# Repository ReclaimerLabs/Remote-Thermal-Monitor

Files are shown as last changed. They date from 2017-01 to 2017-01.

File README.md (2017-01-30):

# Introduction

This board is a remote thermocouple monitor. It is pretty much a direct implementation of [**App Note SBAA189**](http://www.ti.com/lit/an/sbaa189/sbaa189.pdf) from TI. It uses a TI ADS1118 to read the thermocouple and a Particle Photon to connect via WiFi to the Internet. 

The first intended use was to monitor furnances in a materials science laboratory, providing a way for researchers to check on the health of the furnance from home without having to physically go to the lab. 

# Getting Started

The fastest way to get started is to run the Particle app on your phone to claim the Photon, then flash the example app through the Web IDE. Detailed step-by-step instructions are located [**here**](https://www.reclaimerlabs.com/blog/2016/12/29/wifi-thermocouple-monitor). The example app updates the temperature to the SparkFun Data stream and the Particle cloud once every five minutes or so. 

You can find the firmware libraries on github for the [**ADS1118**](https://github.com/ReclaimerLabs/ReclaimerLabs_ADS1118) and for [**thermocouples**](https://github.com/ReclaimerLabs/ReclaimerLabs_Thermocouple). 

# Questions and Comments

If you have questions or comments, you can email me directly at jason@reclaimerlabs.com. 

# License

The MIT License (MIT)

Copyright 2017 Jason Cerundolo

Permission is hereby granted, free of charge, to any person obtaining a copy of this hardware, software, and associated documentation files (the "Product"), to deal in the Product without restriction, including without limitation the rights to use, copy, modify, merge, publish, distribute, sublicense, and/or sell copies of the Product, and to permit persons to whom the Product is furnished to do so, subject to the following conditions:

The above copyright notice and this permission notice shall be included in all copies or substantial portions of the Product.

THE PRODUCT IS PROVIDED "AS IS", WITHOUT WARRANTY OF ANY KIND, EXPRESS OR IMPLIED, INCLUDING BUT NOT LIMITED TO THE WARRANTIES OF MERCHANTABILITY, FITNESS FOR A PARTICULAR PURPOSE AND NONINFRINGEMENT. IN NO EVENT SHALL THE AUTHORS OR COPYRIGHT HOLDERS BE LIABLE FOR ANY CLAIM, DAMAGES OR OTHER LIABILITY, WHETHER IN AN ACTION OF CONTRACT, TORT OR OTHERWISE, ARISING FROM, OUT OF OR IN CONNECTION WITH THE PRODUCT OR THE USE OR OTHER DEALINGS IN THE PRODUCT.

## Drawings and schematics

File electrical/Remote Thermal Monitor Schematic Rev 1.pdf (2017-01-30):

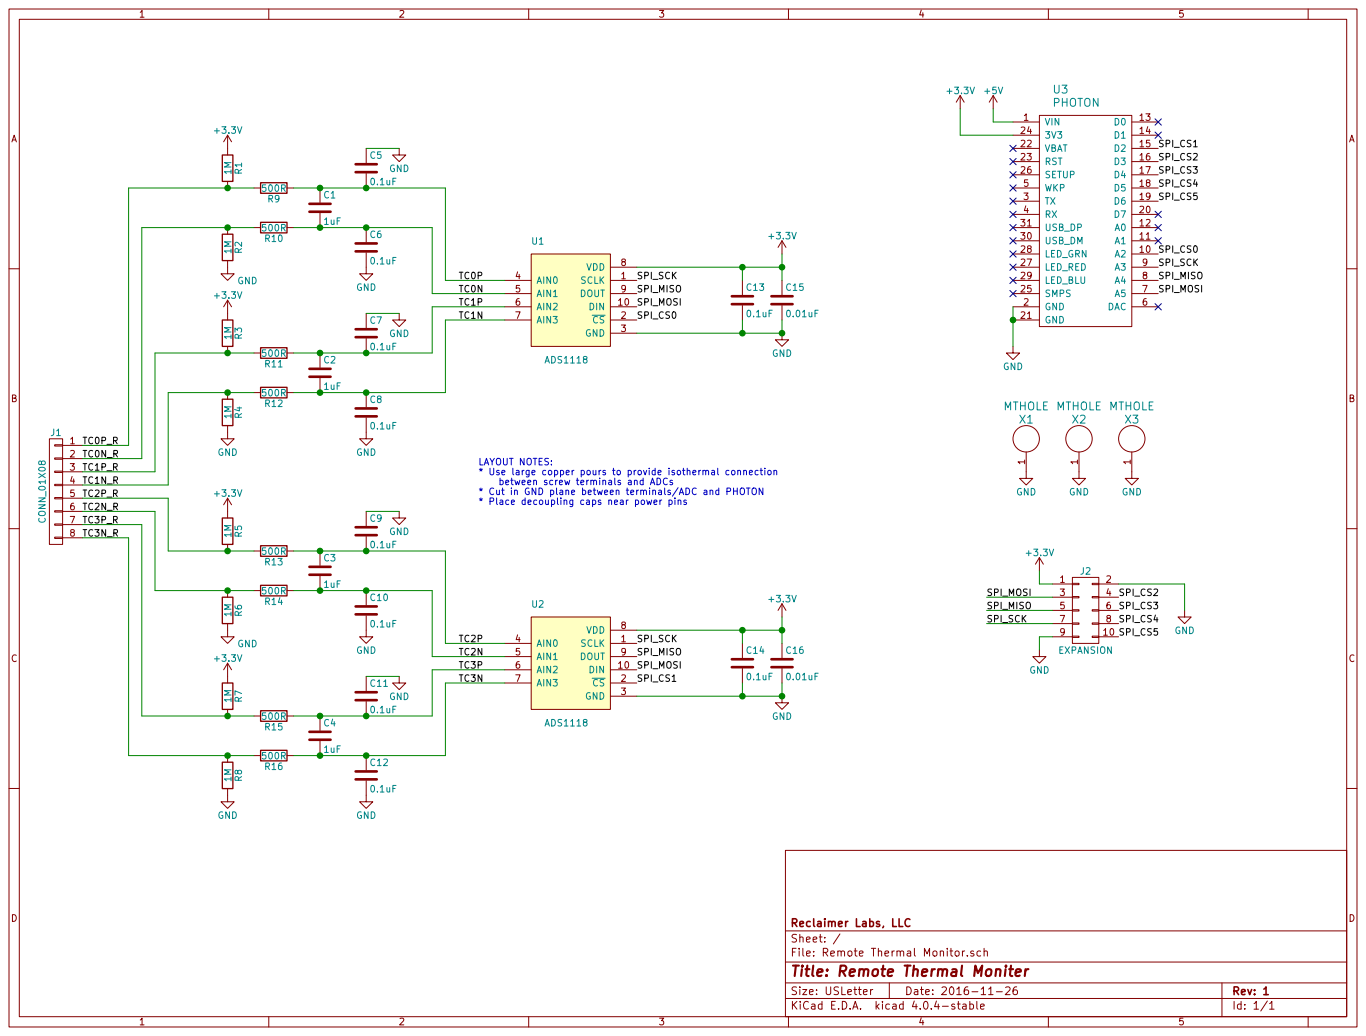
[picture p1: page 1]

* Place decoupling caps near power pins 12345678

LAYOUT NOTES: * Use large copper pours to provide isothermal connection
between screw terminals and ADCs
* Cut in GND plane between terminals/ADC and PHOTON

Id: 1/1 Title: Remote Thermal Moniter File: Remote Thermal Monitor.sch Sheet: / Reclaimer Labs, LLC

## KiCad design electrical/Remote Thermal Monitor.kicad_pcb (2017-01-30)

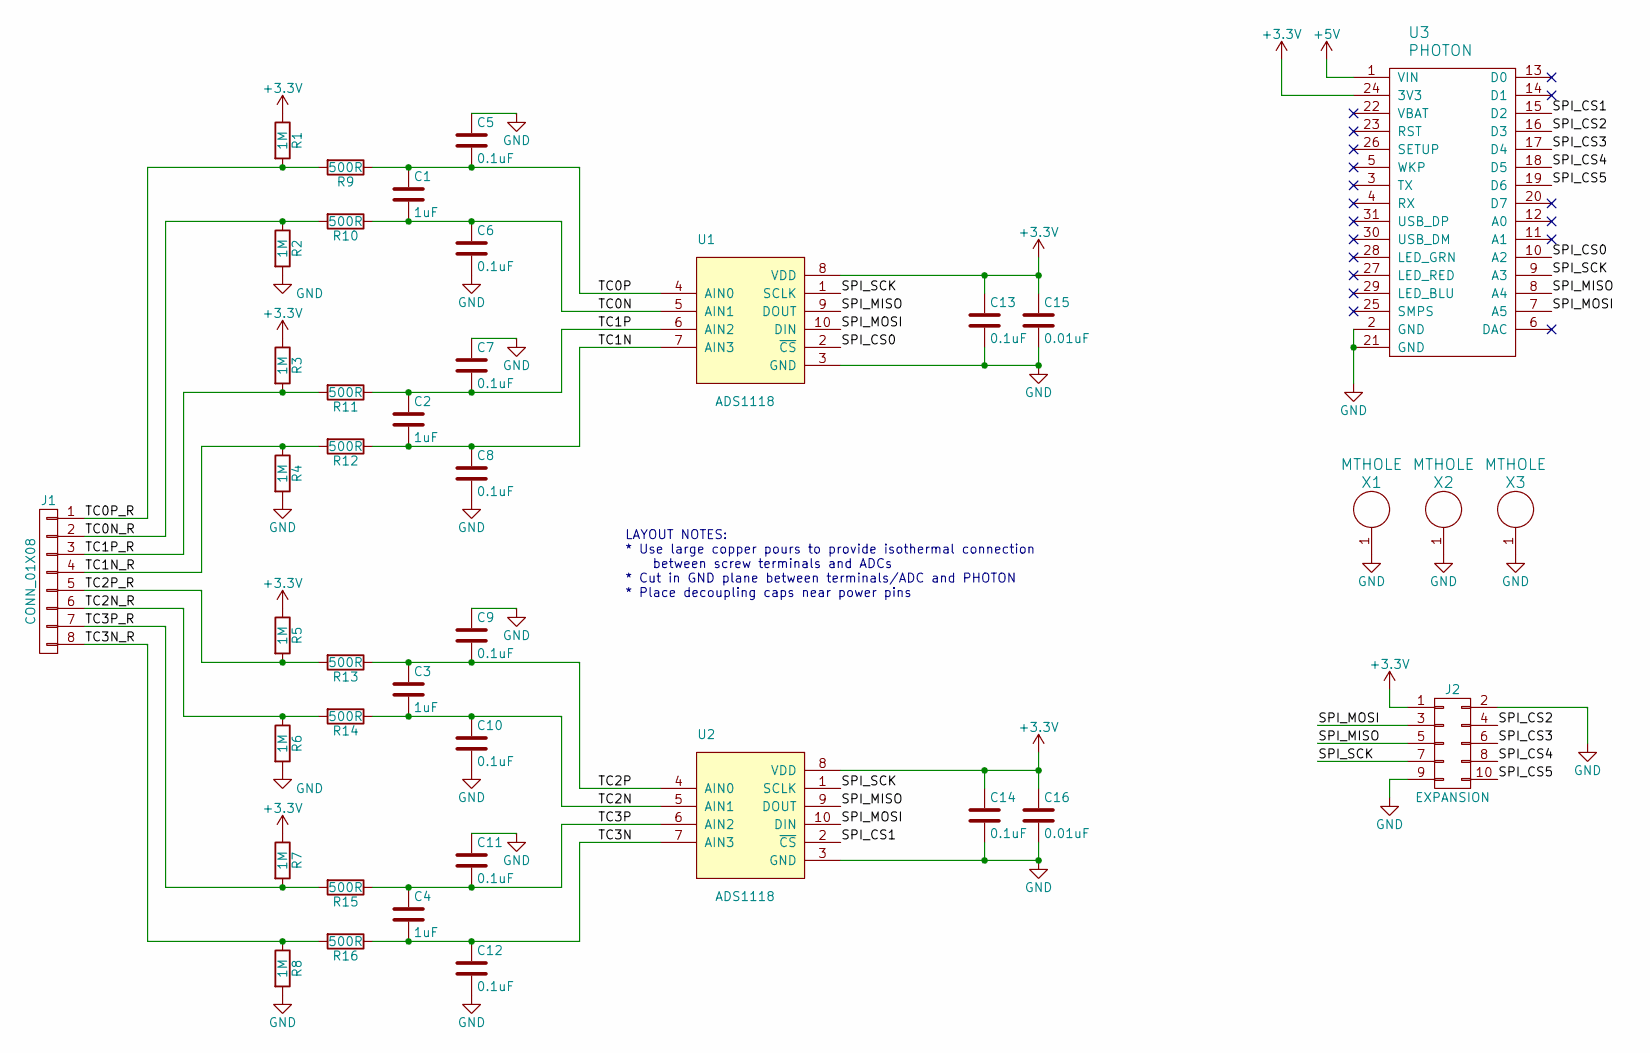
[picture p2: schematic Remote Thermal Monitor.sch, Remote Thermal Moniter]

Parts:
C1, C2, C3, C4: 1uF; C_0603
C5, C6, C7, C8, C9, C10, C11, C12, C13, C14: 0.1uF; C_0603
C15, C16: 0.01uF; C_0603
J1: CONN_01X08; TERM-BLOCK-3.5MM-8; Manufacturer Part Number OSTTE080104
J2: EXPANSION; HEADER_10_POL; Manufacturer Part Number 302-S101
R1, R2, R3, R4, R5, R6, R7, R8: 1M; C_0603
R9, R10, R11, R12, R13, R14, R15, R16: 500R; C_0603
U1, U2: ADS1118; VSSOP-10
U3: PHOTON
X1, X2, X3: MTHOLE; MountingHole_3.5mm_Pad_Via

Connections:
+3V3: C13.1, C14.1, C15.1, C16.1, J2.1, R1.1, R3.1, R5.1, R7.1, U1.8 (VDD), U2.8 (VDD), U3.24 (3V3)
+5V: U3.1 (VIN)
/SPI_CS0: U1.2 (~CS), U3.10 (A2)
/SPI_CS1: U2.2 (~CS), U3.15 (D2)
/SPI_CS2: J2.4, U3.16 (D3)
/SPI_CS3: J2.6, U3.17 (D4)
/SPI_CS4: J2.8, U3.18 (D5)
/SPI_CS5: J2.10, U3.19 (D6)
/SPI_MISO: J2.5, U1.9 (DOUT), U2.9 (DOUT), U3.8 (A4)
/SPI_MOSI: J2.3, U1.10 (DIN), U2.10 (DIN), U3.7 (A5)
/SPI_SCK: J2.7, U1.1 (SCLK), U2.1 (SCLK), U3.9 (A3)
/TC0N: C1.2, C6.1, R10.1, U1.5 (AIN1)
/TC0N_R: J1.2, R2.1, R10.2
/TC0P: C1.1, C5.2, R9.1, U1.4 (AIN0)
/TC0P_R: J1.1, R1.2, R9.2
/TC1N: C2.2, C8.1, R12.1, U1.7 (AIN3)
/TC1N_R: J1.4, R4.1, R12.2
/TC1P: C2.1, C7.2, R11.1, U1.6 (AIN2)
/TC1P_R: J1.3, R3.2, R11.2
/TC2N: C3.2, C10.1, R14.1, U2.5 (AIN1)
/TC2N_R: J1.6, R6.1, R14.2
/TC2P: C3.1, C9.2, R13.1, U2.4 (AIN0)
/TC2P_R: J1.5, R5.2, R13.2
/TC3N: C4.2, C12.1, R16.1, U2.7 (AIN3)
/TC3N_R: J1.8, R8.1, R16.2
/TC3P: C4.1, C11.2, R15.1, U2.6 (AIN2)
/TC3P_R: J1.7, R7.2, R15.2
GND: C5.1, C6.2, C7.1, C8.2, C9.1, C10.2, C11.1, C12.2, C13.2, C14.2, C15.2, C16.2, J2.2, J2.9, R2.2, R4.2, R6.2, R8.2, U1.3 (GND), U2.3 (GND), U3.2 (GND), U3.21 (GND), X1.1, X2.1, X3.1

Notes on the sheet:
LAYOUT NOTES: * Use large copper pours to provide isothermal connection between screw terminals and ADCs * Cut in GND plane between terminals/ADC and PHOTON * Place decoupling caps near power pins

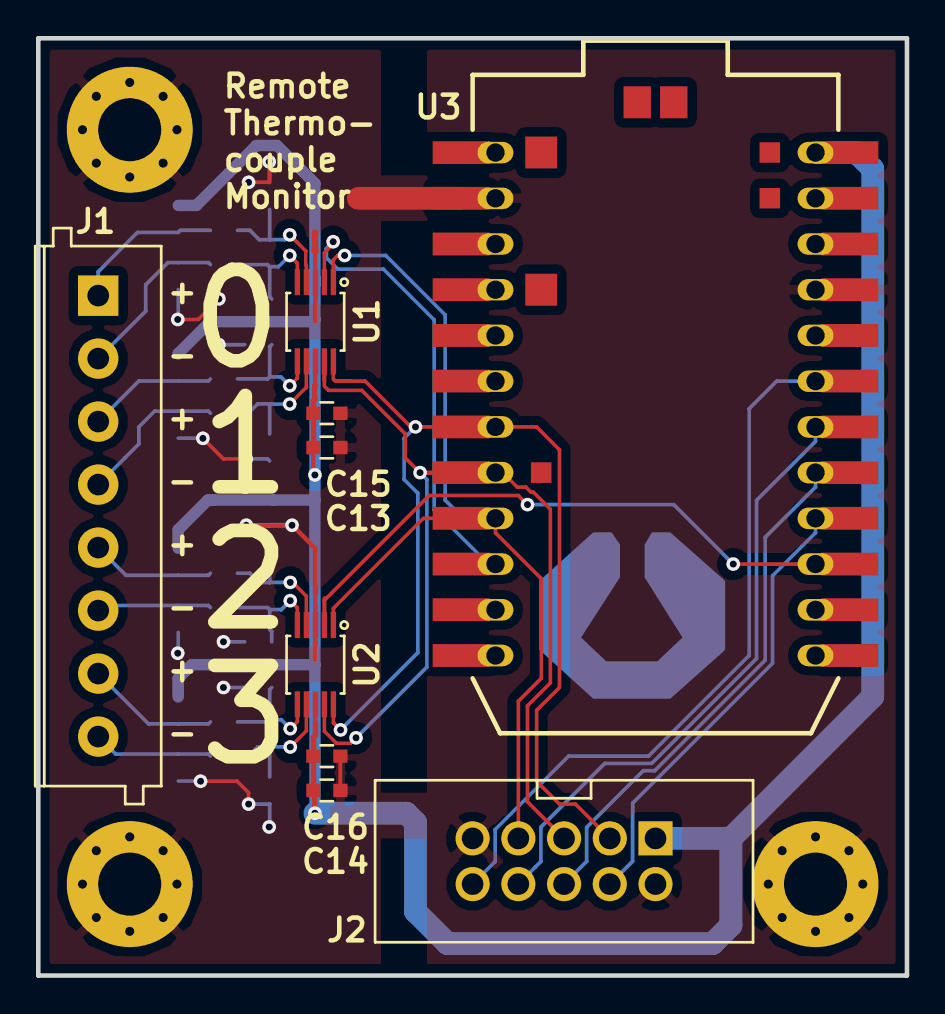
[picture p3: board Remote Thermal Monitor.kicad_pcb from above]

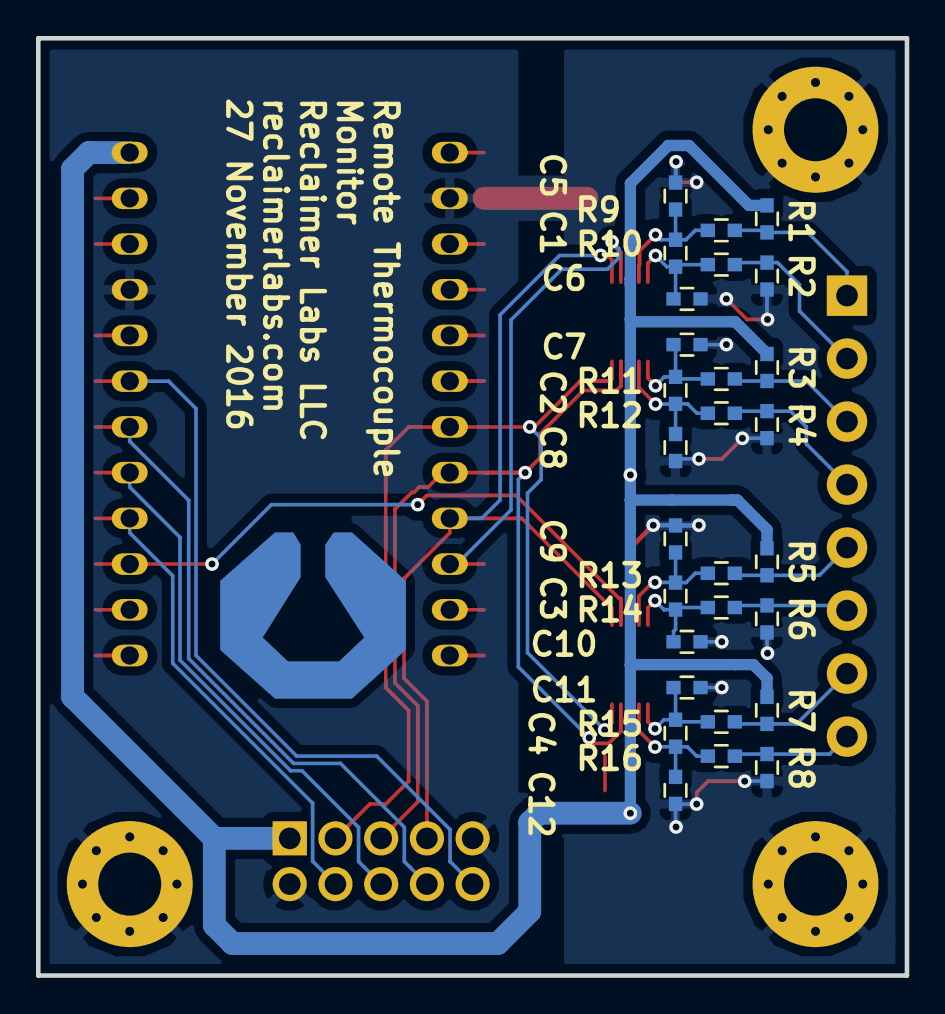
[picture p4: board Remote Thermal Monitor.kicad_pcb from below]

Board: 2 copper layers, 48.3 x 52.1 mm, 40 parts (28 on the bottom side), 27 nets.
